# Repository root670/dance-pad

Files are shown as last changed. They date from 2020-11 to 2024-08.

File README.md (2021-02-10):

# 8020 Extruded Aluminum Dance Pad

*StepMania: Way more fun than a Pelaton bike.*

4-panel dance pad project using a frame built out of 30mm profile 8020
("T-Slot") extruded aluminum including a bar with 9 arrow panels following a
similar design to StepManiaX pads. Each directional arrow has a PCB containing
25 WS2812B RGB LEDs and 4 FSR sensors connected to a Main PCB that acts as a
breakout for a Teensy 4.1.

The firmware reads values from 16 sensors and reports them as gamepad inputs.
I'm using homemade sensors created with two 150mm strips of 1/4" copper tape
attached to 160mm x 20mm transparency film with 4mil Velostat placed across the
top. Wires are soldered to each of the copper tape strips and terminate to
JST-XE connectors at the end to connect to the Arrow Panel PCB. According to
papers I've read, creating FSR in this way will likely lead to less drifting
over time compared to "sandwich" style sensors where Velostat is placed between
two pieces of copper tape. This is similar to the method used by
commercially-produced FSRs.

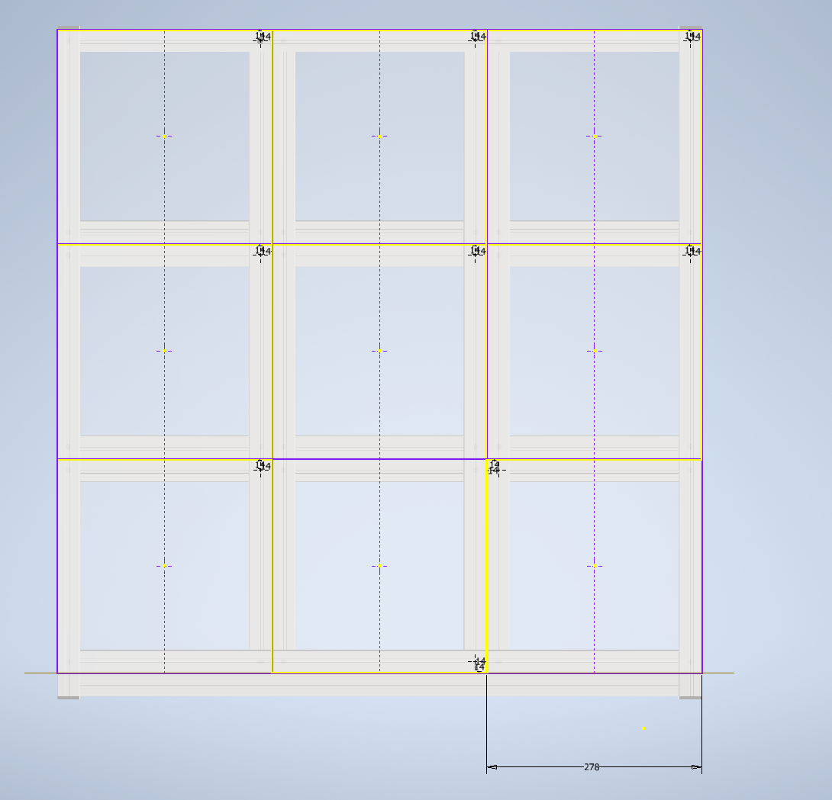
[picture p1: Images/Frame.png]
Frame


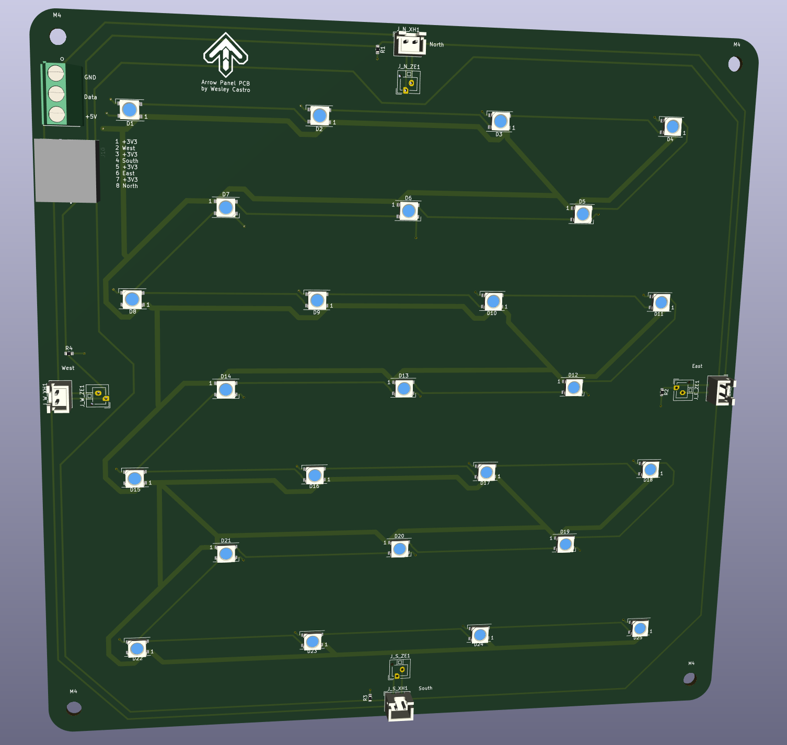
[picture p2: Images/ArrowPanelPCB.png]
Arrow Panel PCB


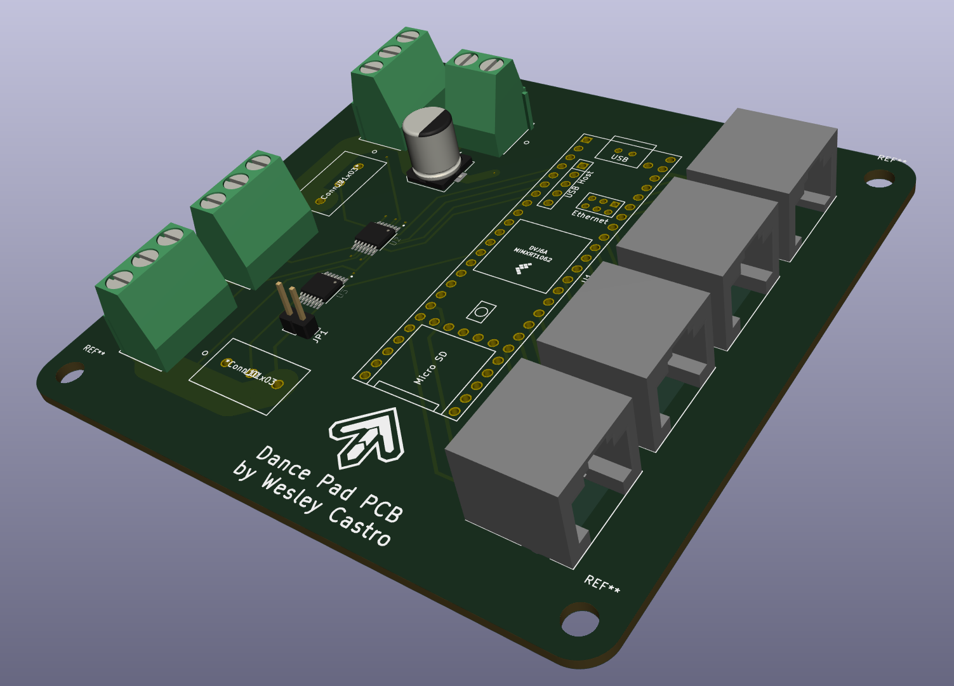
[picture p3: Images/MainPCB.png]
Main PCB


## Motivation

There has been a ton of interest in using force sensitive resistors in dance
pads recently to replace contact-based sensors and many designs have been
created. I decided to create a design for a full pad that is durable but doesn't
require power tools to build. I also wanted to gain experience using Inventor
and KiCad and share my design with others who may find it useful. It's certainly
not the best design, but the experience I've gained in the process is
invaluable.

Having personal projects to come back to is a great and productive way to
improve your creative and technical skills, especially during COVID times. And
when the project involves maintaining your physical health, that's even better! I
can't stress enough how rewarding it is to start a project, work on in over the
course of a few months, and see it through to completion. Soapbox aside, I
highly recommend attempting projects for things that seem slightly out of your
abilities. You might be surprised what you're capable of if you stick with it.

## Directory Structure

* `Frame`: Inventor project for the aluminum frame. It houses nine 276mm x 276mm
  x 12mm cast acrylic panels with 2mm clearance between each edge. The back of
  the frame has slots for securing a bar.

* `Arrow PCB`: 2 layer 200mm x 200mm PCB used within each arrow containing 25
  WS2812B V5 LEDs arranged in an alternating 4,3 grid pattern and pins for 4
  FSRs connected using JST-XH and JST-ZE connectors. Created in KiCad. Each FSR
  uses a 330 ohm pull down resistor to ground. The board is connected to the
  Main PCB using a CAT6 cable for the four sensors and screw terminals for the
  LED power, ground, and data lines. The PCB can be rotated to the best location
  to route wires to the Main PCB by denoting the location in the firmware.
  M4-sized terminals are on the corners of the PCB so it can be mounted to the
  frame using 3D printed parts (TODO).

* `Main PCB`: 2 layer ~100mm x ~100mm breakout board for a Teensy 4.1. Wires
  RJ45 connectors for connections coming from 4 Arrow PCBs and screw terminals
  for up 5 LED strands interfaced through 3.3V to 5V logic converters. The
  sensor wires are decoupled with 3.3v wires in the cable to minimize
  interference. Has M4-sized screw terminal to attach to 3D printed mounting
  hardware (TODO).

* `Configurator`: Application to configure and debug the pad written in Python.
  Communicates with the firmware using a serial connection.

* `Firmware`: Code that runs on the Teensy. Reads sensor values, listens for
  serial messages, and controls the LEDs. Uses fixed timings for sending Joypad
  reports and updating the LEDs. The goal is for it to be easy enough to modify
  to support different pad layouts (i.e. 5 panel StepManiaX or Pump It Up pads)

* `Supplemental`: Various helper scripts and files related to this project. All
  of these are optional but may be useful depending on you setup.

## Status

The frame, acrylic panels, and PCB designs have been finalized, fabricated, and
assembled.

The arrows have counter bore screws but I made the larger part of the counter
bore too small (It's a 9.53mm counterbore for a 7.94mm through hole, leaving
~0.8mm radius for the counterbore. Whoops.). It's large enough to fit
button-head M5 screws with a 3D printed spacer but M6 socket and button head
screws will not fit unfortunately. These will work fine with M5 screws but the
lesson learned is to not hastily order things like this in the future :-).

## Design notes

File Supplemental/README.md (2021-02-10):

# Supplemental

Various helper scripts and files related to this project.

## Files

* `lights_bridge.py`: Python script to send output messages for lights from MAME
  to serial devices as a SextetStream. To use this, launch MAME with `-output
  network` or change the `output` setting in `mame.ini` to `network`.

* `ddr.lua`: Lua script for MAME that disables frame skip during the
  initialization sequence of DDR titles. To use this, launch MAME with
  `autoboot_script ddr.lua`.

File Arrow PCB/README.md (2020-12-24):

# Arrow Panel PCB

Board placed under each panel. Houses 25 WS2812B V5 RGB LEDs and connects to 4
FSR sensors using JST-XE or JST-ZH connectors. Connects back to the Main PCB
using a CAT6 cable for the sensors and cables secured to a screw terminal for
the lights.

## Notes

* The pull down resistor used for each sensor may need to be adjusted depending
  on the sensors being used.
* The board requires the "V5" revision of the WS2812B LEDs. The advantage of
  this version is that have an internal capacitor so you don't the need to place
  an external capacitor between the positive voltage and ground pins. If an
  older version is used the LEDs will likely be damaged when they receive power.

## Issues

* I was unable to get the LEDs to work reliably using multiple 3.3v and 5v
  microcontrollers and WS2812B libraries. I believe there is something wrong
  with my design or the LEDs sourced by LCSC were not actually the 5V
  variations. LCSC has been unable to confirm if they are actually the V5
  version.
* The PCB is too big to fit within the frame underneath the panels when using
  corner brackets. As a workaround the PCBs need to be placed underneath the
  frame.

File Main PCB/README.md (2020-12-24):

# Main PCB

Breakout board for a Teensy 4.1 with 4 RJ45 connectors to connect the sensors
from each arrow and 5 3-pin screw terminals to connect the lights. An additional
3-pin screw terminal is available for an auxilary lighting strip.

## Notes

* At least a 6A 5V DC power supply is needed to support displaying all LEDs at
  maximum brightness.

## Issues

* The LED pins for the four arrows  don't allow for "parallel output" with
  FastLED or WS2812Serial because I didn't realize only a subset of pins support
  that feature. The AuxLED pin however should work with parallel output.
* Silkscreen labels are missing for most connectors.

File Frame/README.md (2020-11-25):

# Frame

Frame designed in Inventor 2021 using 30mm 8020 aluminum extrusions.

## Notes

* My design uses a 975mm high bar secured to the bottom row of the pad but it is
   not included in the Inventor project.
* The panels are 276mm x 276mm x 12mm cast acrylic with 3.17mm (1/8") rounded
   corners (note that the drawin shows these as 2mm, but the shop that
   fabricated them (TAP Plastics) only had a 1/8" roundover bit) and counterbore screws. They
   support M5 screws with a ~2mm OD standoff. The standoffs should allow for
   consistent pressure across all panels. A drawing of the panel specifications
   can be found in `Arrow Panel.pdf`.
* I plan to use 5/16" thick HDPE foaming underneath the corners of each panel
   but have not finalized this aspect.
* The stationary arrows will need risers to make them ~4mm higher than the arrow
  panels. This can be done with metal washers or 3D printed inserts.
* There are 2mm of space between the edges of each arrow.
* The assembly requires an 8020 frame generator library to be added to the
   content center to load correctly:
   https://grabcad.com/library/8020-profile-extrusions-and-inventor-frame-generator-library-content-center-1

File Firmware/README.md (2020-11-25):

# Dance Pad Firmware

Firmware for implementing a dance pad. Analog sensor inputs are converted to
buttons on an HID joypad.

## Features

* Auto-calibration of FSR sensors using a moving baseline.
* Serial interface for configuration and debugging.

## Features (planned)

* Activate RBG LEDs in arrow PCBs based on SextetStream protocol over Serial interface.

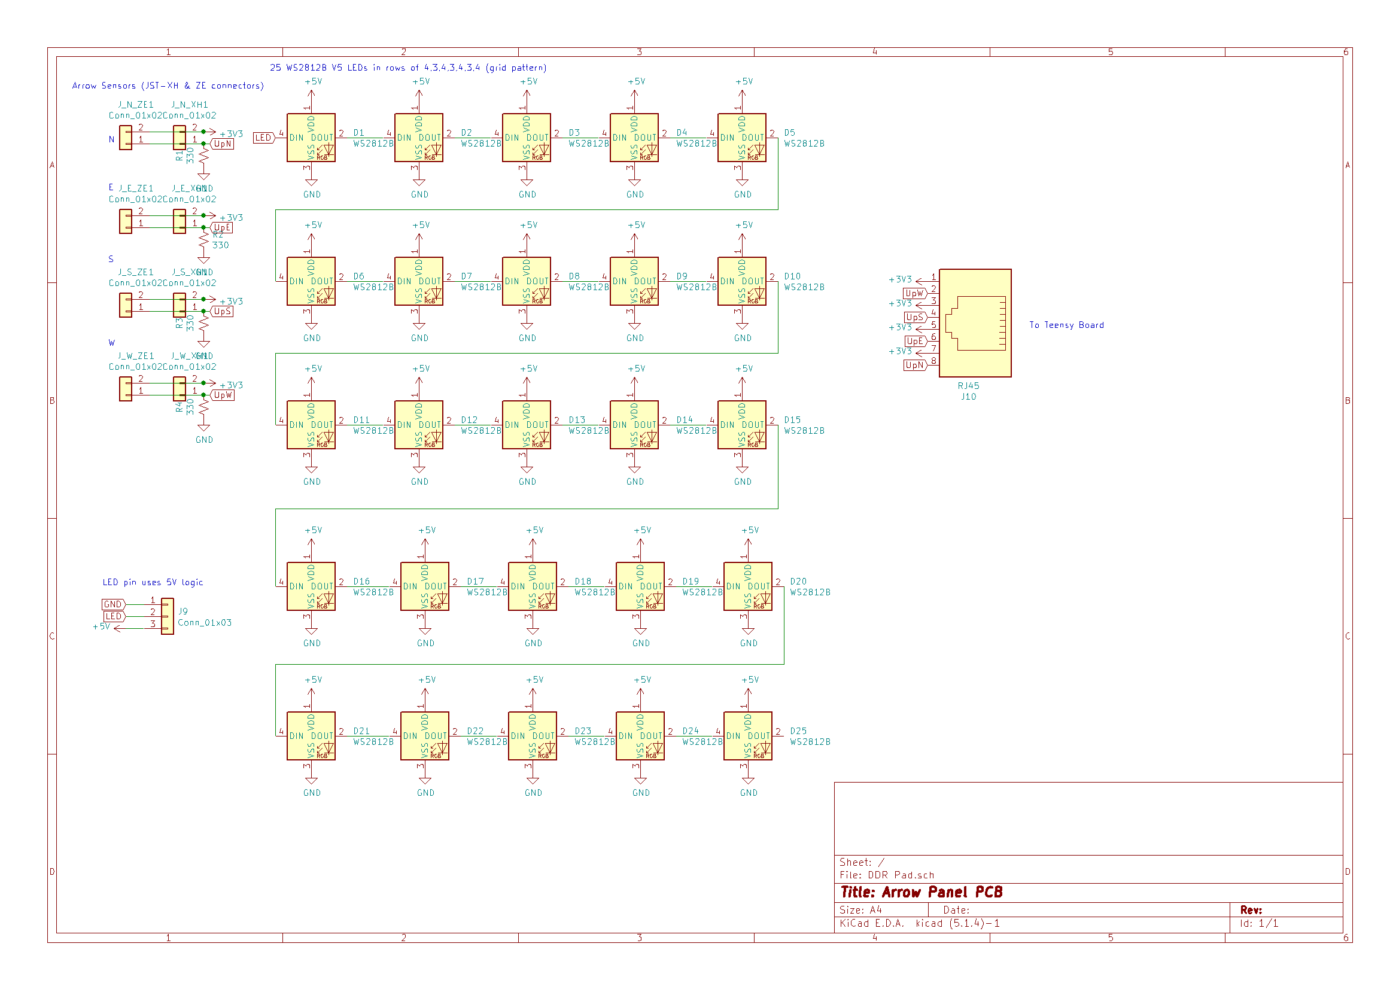
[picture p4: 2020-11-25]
Arrow PCB/Schematic.png

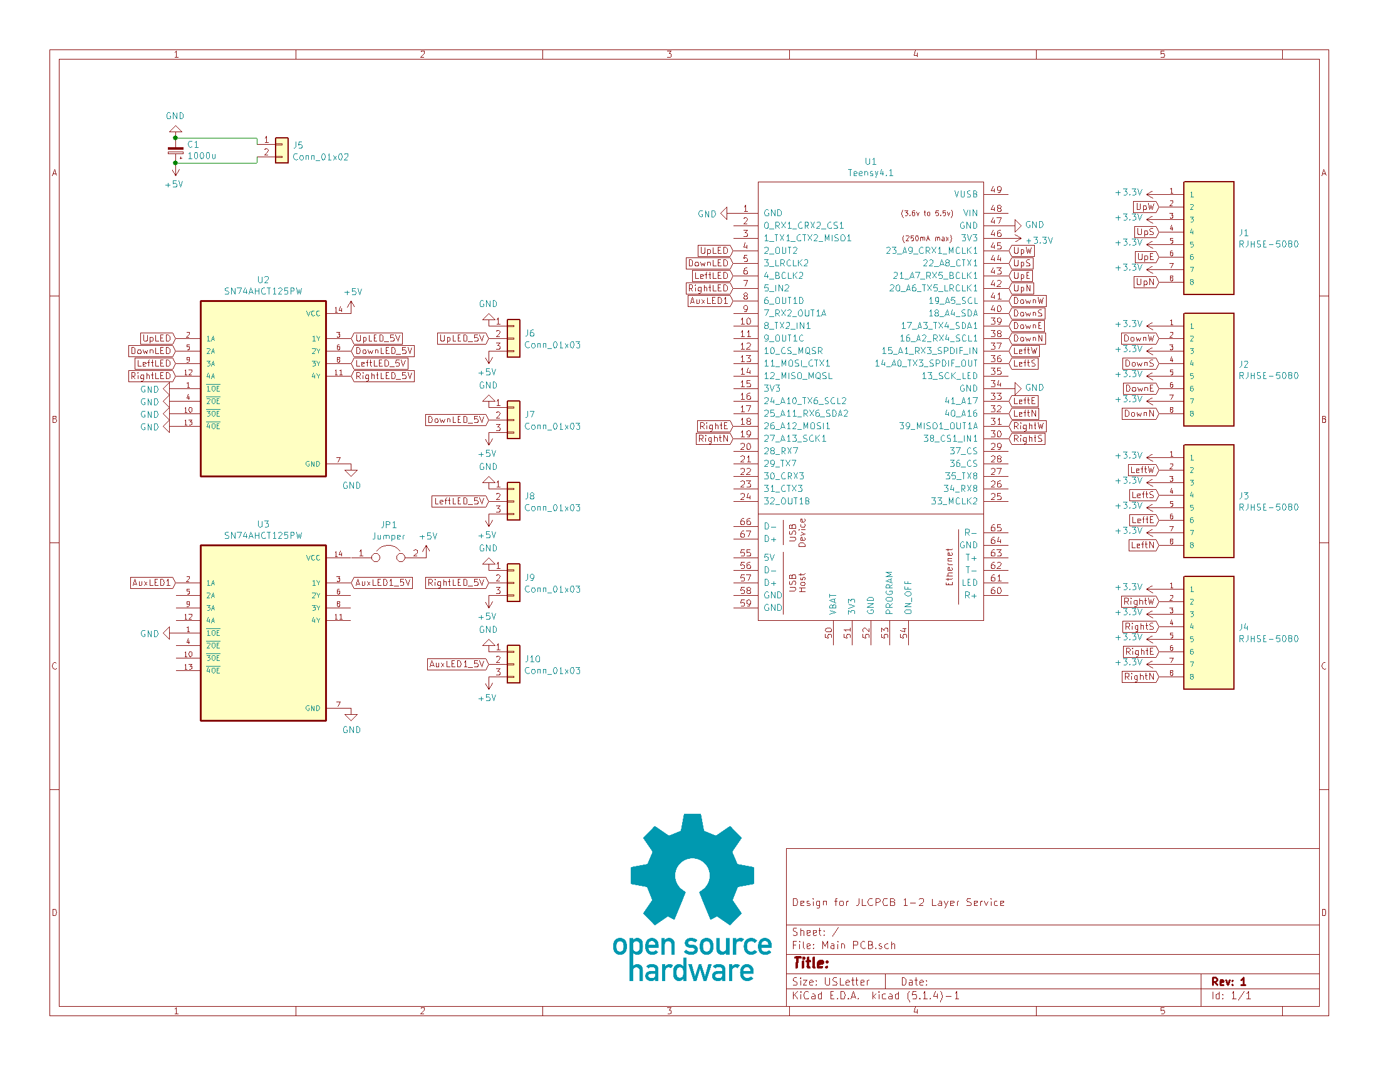
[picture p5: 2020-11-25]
Main PCB/Schematic.png

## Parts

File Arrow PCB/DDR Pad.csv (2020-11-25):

Comment | Designator | Footprint | LCSC
WS2812B | D1,D2,D3,D4,D5,D6,D7,D8,D9,D10,D11,D12,D13,D14,D15,D16,D17,D18,D19,D20,D21,D22,D23,D24,D25 | LED_SMD:LED_WS2812B_PLCC4_5.0x5.0mm_P3.2mm
RJ45 | J10 | RJHSE-5080:AMPHENOL_RJHSE-5080
Conn_01x03 | J9 | footprints:1935174
Conn_01x02 | J_E_ZE1,J_S_ZE1,J_W_ZE1,J_N_ZE1 | Connector_JST:JST_ZE_B02B-ZESK-1D_1x02_P1.50mm_Vertical
Conn_01x02 | J_N_XH1,J_E_XH1,J_S_XH1,J_W_XH1 | Connector_JST:JST_XH_B2B-XH-A_1x02_P2.50mm_Vertical
330 | R1,R2,R3,R4 | Resistor_SMD:R_0603_1608Metric

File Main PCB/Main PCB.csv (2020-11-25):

Comment | Designator | Footprint | LCSC
1000u | C1 | Capacitor_SMD:CP_Elec_8x10 | C134755
RJHSE-5080 | J1,J2,J3,J4 | RJHSE-5080:AMPHENOL_RJHSE-5080
Conn_01x02 | J5 | footprints:1935161
Conn_01x03 | J6,J7,J8,J9,J10 | footprints:1935174
Jumper | JP1 | Connector_PinHeader_2.54mm:PinHeader_1x02_P2.54mm_Vertical
Teensy4.1 | U1 | Main PCB:Teensy41
SN74AHCT125PW | U2,U3 | SN74AHCT125PW:SOP65P640X120-14N | C36365

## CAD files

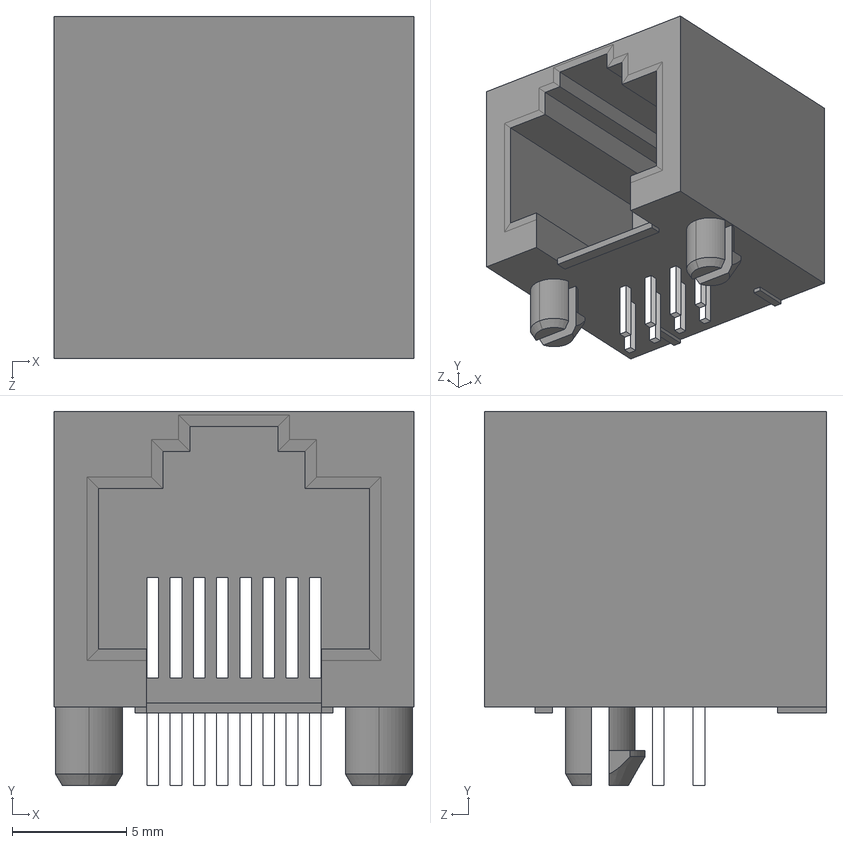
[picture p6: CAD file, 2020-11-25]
Arrow PCB/RJHSE-5080/RJHSE-5080.step
15.7 x 16.4 x 15.0 mm

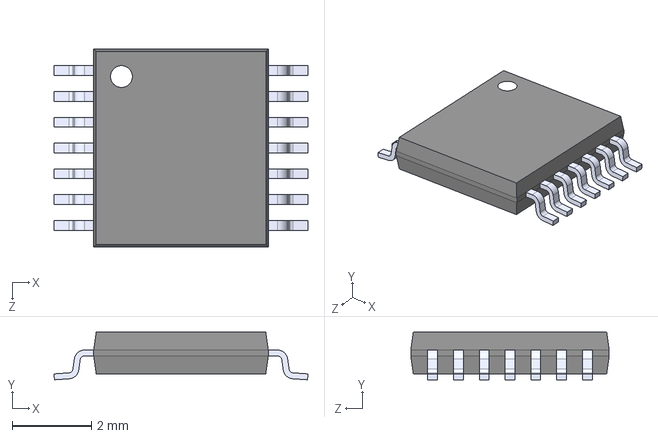
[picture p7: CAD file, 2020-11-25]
Main PCB/SN74AHCT125PW/SN74AHCT125PW.step
6.40 x 1.20 x 5.00 mm

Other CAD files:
Arrow PCB/DDR Pad 1.ipt
Arrow PCB/DDR Pad.ipt
Frame/30mm.iam
Frame/30mm/Frame/1604985380858.ipt
Frame/30mm/Frame/1604985393171.ipt
Frame/30mm/Frame/1604985569969.ipt
Frame/30mm/Frame/1604985569996.ipt
Frame/30mm/Frame/1604985570023.ipt
Frame/30mm/Frame/1604985570057.ipt
Frame/30mm/Frame/1604985570057.newVer.ipt
Frame/30mm/Frame/1604985570084.ipt
Frame/30mm/Frame/1604985570084.newVer.ipt
Frame/30mm/Frame/1604985570111.ipt
Frame/30mm/Frame/1604985570138.ipt
Frame/30mm/Frame/1604985570165.ipt
Frame/30mm/Frame/1604985570191.ipt
Frame/30mm/Frame/1604985708951.ipt
Frame/30mm/Frame/1605505222055.ipt
Frame/30mm/Frame/1605505434790.ipt
Frame/30mm/Frame/Frame 1604985372804.iam
Frame/30mm/Frame/OldVersions/1604985380858.0004.ipt
Frame/30mm/Frame/OldVersions/1604985393171.0004.ipt
Frame/30mm/Frame/OldVersions/1604985569969.0004.ipt
Frame/30mm/Frame/OldVersions/1604985569996.0004.ipt
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

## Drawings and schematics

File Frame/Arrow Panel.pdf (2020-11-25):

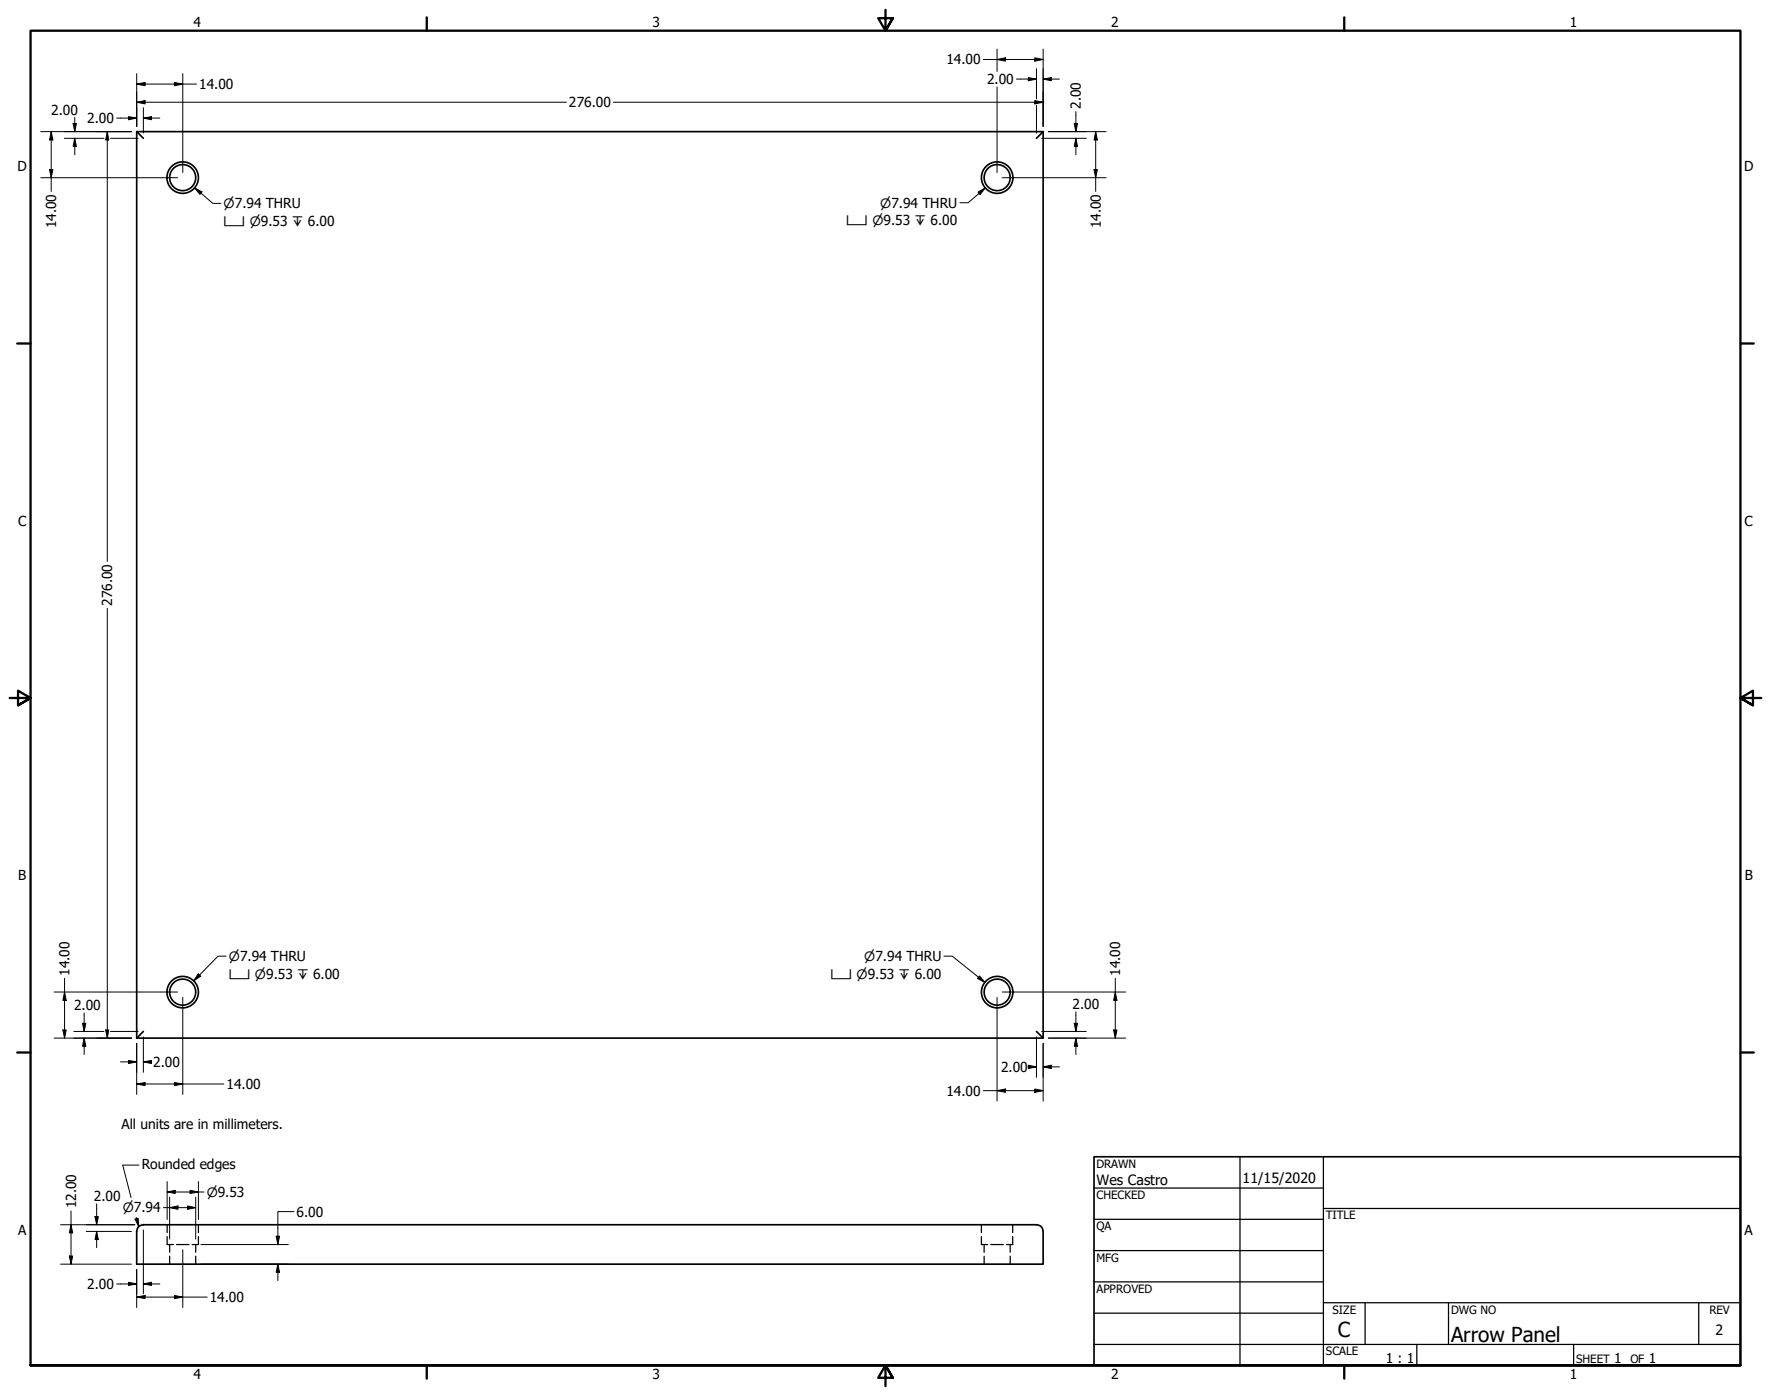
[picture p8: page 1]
Rounded edges

All units are in millimeters.

DRAWN Wes Castro | 11/15/2020

CHECKED

MFG

APPROVED

SIZE C | DWG NO Arrow Panel | REV 2

SCALE 1 : 1 | | SHEET 1 OF 1

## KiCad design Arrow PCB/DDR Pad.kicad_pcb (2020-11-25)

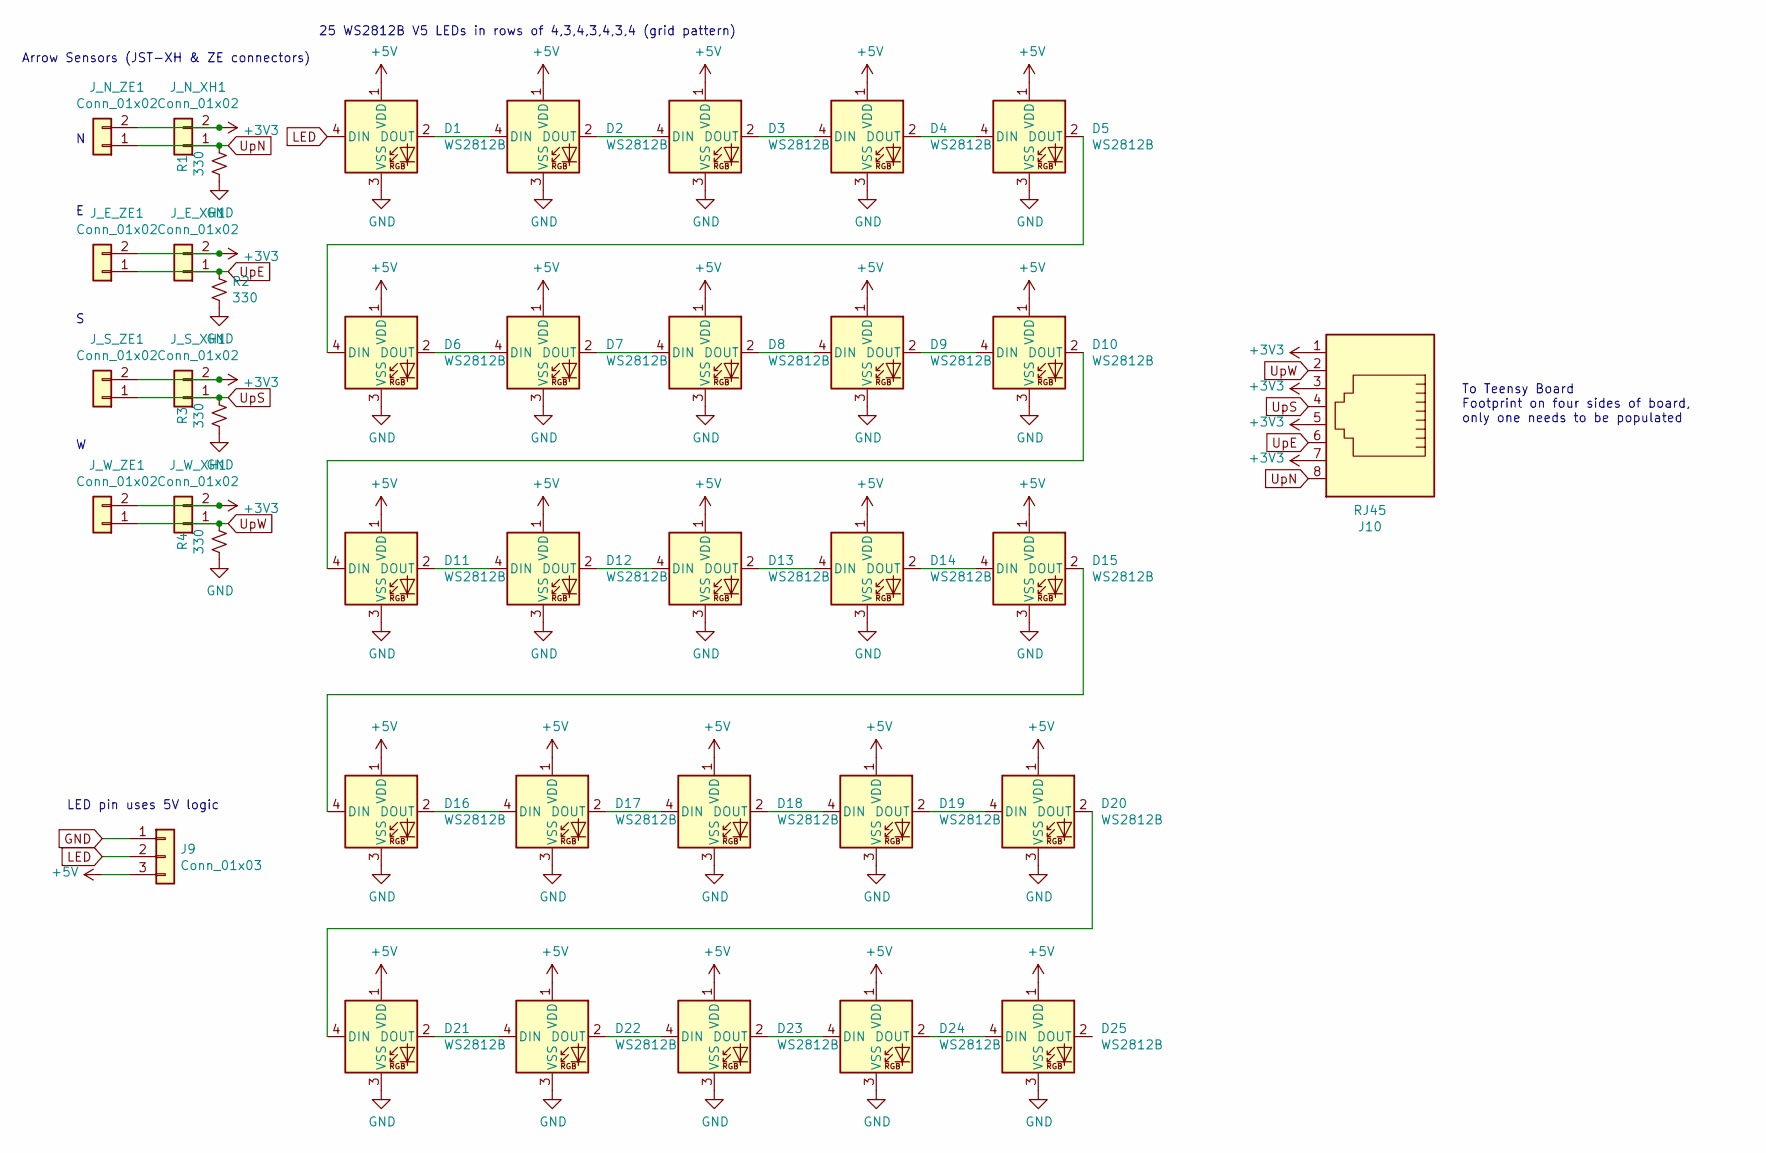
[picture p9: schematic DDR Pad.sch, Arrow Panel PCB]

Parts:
D1, D2, D3, D4, D5, D6, D7, D8, D9, D10, D11, D12, D13, D14, D15, D16, D17, D18, D19, D20, D21, D22, D23, D24, D25: WS2812B; LED_WS2812B_PLCC4_5.0x5.0mm_P3.2mm
J9: Conn_01x03; 1935174
J10: RJ45; AMPHENOL_RJHSE-5080
J_E_XH1: Conn_01x02; JST_XH_B2B-XH-A_1x02_P2.50mm_Vertical
J_E_ZE1: Conn_01x02; JST_ZE_B02B-ZESK-1D_1x02_P1.50mm_Vertical
J_N_XH1: Conn_01x02; JST_XH_B2B-XH-A_1x02_P2.50mm_Vertical
J_N_ZE1: Conn_01x02; JST_ZE_B02B-ZESK-1D_1x02_P1.50mm_Vertical
J_S_XH1: Conn_01x02; JST_XH_B2B-XH-A_1x02_P2.50mm_Vertical
J_S_ZE1: Conn_01x02; JST_ZE_B02B-ZESK-1D_1x02_P1.50mm_Vertical
J_W_XH1: Conn_01x02; JST_XH_B2B-XH-A_1x02_P2.50mm_Vertical
J_W_ZE1: Conn_01x02; JST_ZE_B02B-ZESK-1D_1x02_P1.50mm_Vertical
R1, R2, R3, R4: 330; R_0603_1608Metric

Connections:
+3V3: J10.1, J10.3, J10.5, J10.7, J_E_XH1.2, J_E_ZE1.2, J_N_XH1.2, J_N_ZE1.2, J_S_XH1.2, J_S_ZE1.2, J_W_XH1.2, J_W_ZE1.2
+5V: D1.1 (VDD), D2.1 (VDD), D3.1 (VDD), D4.1 (VDD), D5.1 (VDD), D6.1 (VDD), D7.1 (VDD), D8.1 (VDD), D9.1 (VDD), D10.1 (VDD), D11.1 (VDD), D12.1 (VDD), D13.1 (VDD), D14.1 (VDD), D15.1 (VDD), D16.1 (VDD), D17.1 (VDD), D18.1 (VDD), D19.1 (VDD), D20.1 (VDD), D21.1 (VDD), D22.1 (VDD), D23.1 (VDD), D24.1 (VDD), D25.1 (VDD), J9.3
GND: D1.3 (VSS), D2.3 (VSS), D3.3 (VSS), D4.3 (VSS), D5.3 (VSS), D6.3 (VSS), D7.3 (VSS), D8.3 (VSS), D9.3 (VSS), D10.3 (VSS), D11.3 (VSS), D12.3 (VSS), D13.3 (VSS), D14.3 (VSS), D15.3 (VSS), D16.3 (VSS), D17.3 (VSS), D18.3 (VSS), D19.3 (VSS), D20.3 (VSS), D21.3 (VSS), D22.3 (VSS), D23.3 (VSS), D24.3 (VSS), D25.3 (VSS), J9.1, R1.2, R2.2, R3.2, R4.2
LED: D1.4 (DIN), J9.2
unnamed: D1.2 (DOUT), D2.4 (DIN)
unnamed: D2.2 (DOUT), D3.4 (DIN)
unnamed: D3.2 (DOUT), D4.4 (DIN)
unnamed: D4.2 (DOUT), D5.4 (DIN)
unnamed: D5.2 (DOUT), D6.4 (DIN)
unnamed: D6.2 (DOUT), D7.4 (DIN)
unnamed: D7.2 (DOUT), D8.4 (DIN)
unnamed: D8.2 (DOUT), D9.4 (DIN)
unnamed: D10.2 (DOUT), D11.4 (DIN)
unnamed: D9.2 (DOUT), D10.4 (DIN)
unnamed: D11.2 (DOUT), D12.4 (DIN)
unnamed: D12.2 (DOUT), D13.4 (DIN)
unnamed: D13.2 (DOUT), D14.4 (DIN)
unnamed: D14.2 (DOUT), D15.4 (DIN)
unnamed: D15.2 (DOUT), D16.4 (DIN)
unnamed: D16.2 (DOUT), D17.4 (DIN)
unnamed: D17.2 (DOUT), D18.4 (DIN)
unnamed: D18.2 (DOUT), D19.4 (DIN)
unnamed: D19.2 (DOUT), D20.4 (DIN)
unnamed: D20.2 (DOUT), D21.4 (DIN)
unnamed: D21.2 (DOUT), D22.4 (DIN)
unnamed: D22.2 (DOUT), D23.4 (DIN)
unnamed: D23.2 (DOUT), D24.4 (DIN)
unnamed: D24.2 (DOUT), D25.4 (DIN)
UpE: J10.6, J_E_XH1.1, J_E_ZE1.1, R2.1
UpN: J10.8, J_N_XH1.1, J_N_ZE1.1, R1.1
UpS: J10.4, J_S_XH1.1, J_S_ZE1.1, R3.1
UpW: J10.2, J_W_XH1.1, J_W_ZE1.1, R4.1

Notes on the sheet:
LED pin uses 5V logic
Arrow Sensors (JST-XH & ZE connectors)
25 WS2812B V5 LEDs in rows of 4,3,4,3,4,3,4 (grid pattern)
To Teensy Board Footprint on four sides of board, only one needs to be populated

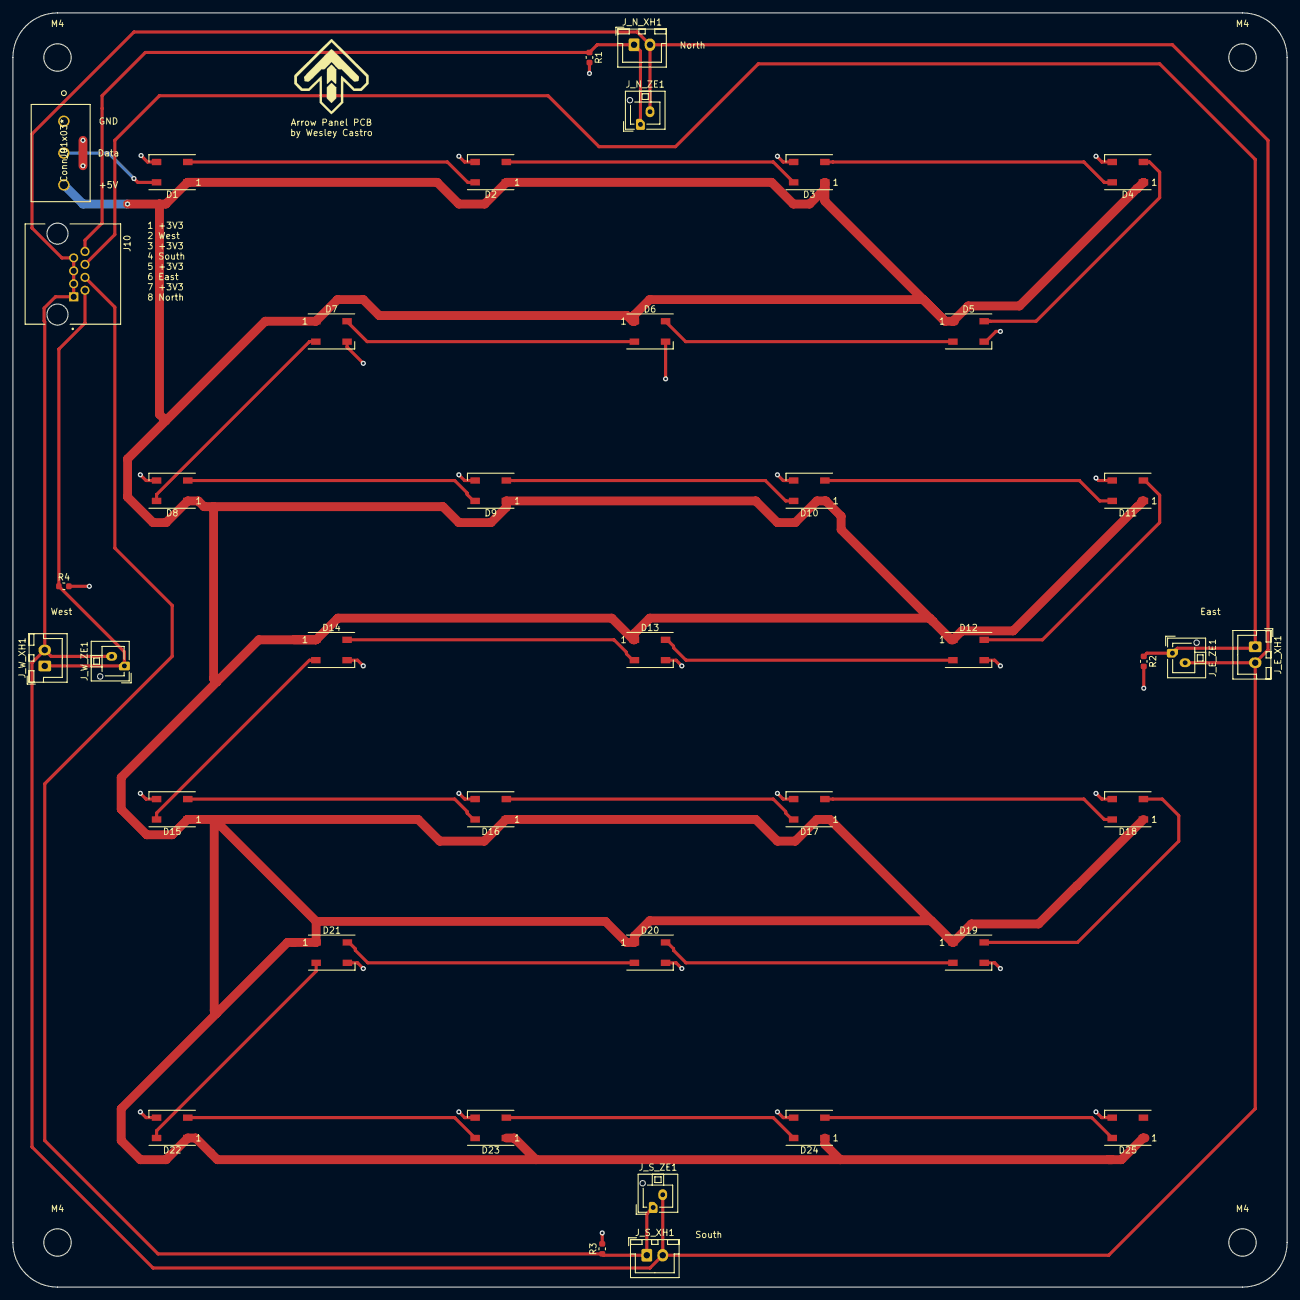
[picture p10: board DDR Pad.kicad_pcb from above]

Board: 2 copper layers, 200.0 x 200.0 mm, 43 parts (0 on the bottom side), 32 nets.

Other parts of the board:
M4, M4#2, M4#3, M4#4: MountingHole_4.3mm_M4

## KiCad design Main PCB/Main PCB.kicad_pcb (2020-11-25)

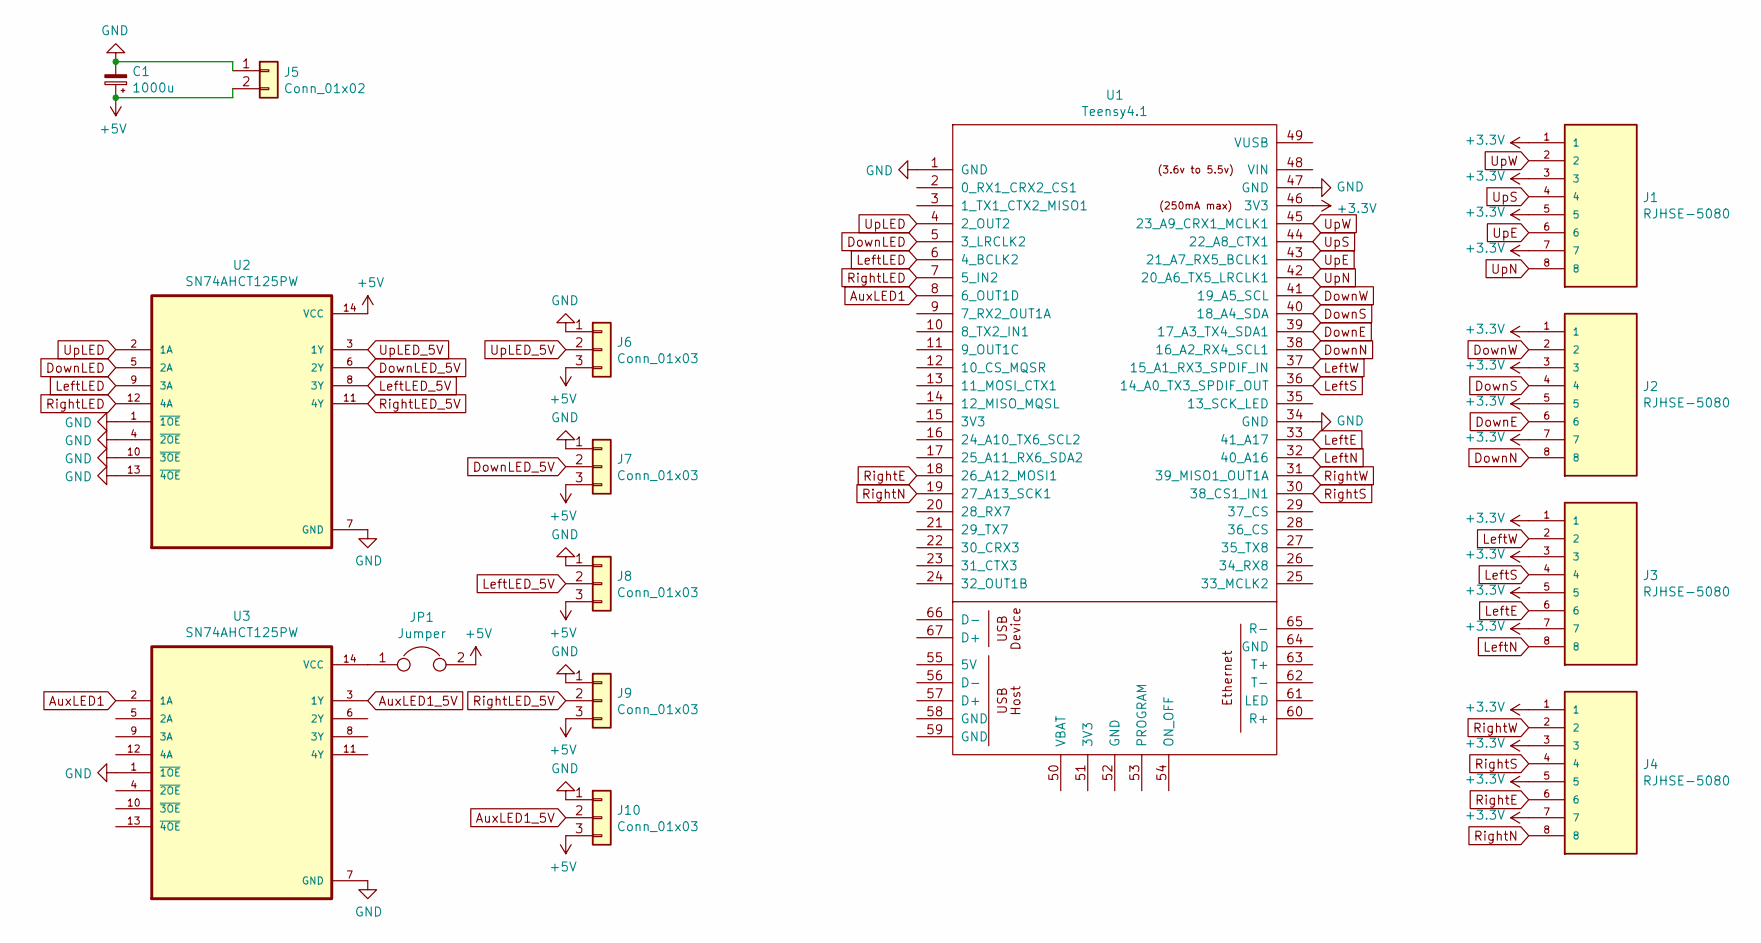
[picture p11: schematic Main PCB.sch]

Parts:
C1: 1000u; CP_Elec_8x10; LCSC C134755
J1, J2, J3, J4: RJHSE-5080; AMPHENOL_RJHSE-5080; PARTREV G
J5: Conn_01x02; 1935161
J6, J7, J8, J9, J10: Conn_01x03; 1935174
JP1: Jumper; PinHeader_1x02_P2.54mm_Vertical
U1: Teensy4.1; Teensy41
U2, U3: SN74AHCT125PW; SOP65P640X120-14N

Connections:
+3V3: J1.1, J1.3, J1.5, J1.7, J2.1, J2.3, J2.5, J2.7, J3.1, J3.3, J3.5, J3.7, J4.1, J4.3, J4.5, J4.7, U1.46 (3V3)
+5V: C1.1, J5.2, J6.3, J7.3, J8.3, J9.3, J10.3, JP1.2, U2.14 (VCC)
AuxLED1: U1.8 (6_OUT1D), U3.2 (1A)
AuxLED1_5V: J10.2, U3.3 (1Y)
DownE: J2.6, U1.39 (17_A3_TX4_SDA1)
DownLED: U1.5 (3_LRCLK2), U2.5 (2A)
DownLED_5V: J7.2, U2.6 (2Y)
DownN: J2.8, U1.38 (16_A2_RX4_SCL1)
DownS: J2.4, U1.40 (18_A4_SDA)
DownW: J2.2, U1.41 (19_A5_SCL)
GND: C1.2, J5.1, J6.1, J7.1, J8.1, J9.1, J10.1, U1.1 (GND), U1.34 (GND), U1.47 (GND), U2.1 (~1OE), U2.4 (~2OE), U2.7 (GND), U2.10 (~3OE), U2.13 (~4OE), U3.1 (~1OE), U3.7 (GND)
LeftE: J3.6, U1.33 (41_A17)
LeftLED: U1.6 (4_BCLK2), U2.9 (3A)
LeftLED_5V: J8.2, U2.8 (3Y)
LeftN: J3.8, U1.32 (40_A16)
LeftS: J3.4, U1.36 (14_A0_TX3_SPDIF_OUT)
LeftW: J3.2, U1.37 (15_A1_RX3_SPDIF_IN)
unnamed: JP1.1, U3.14 (VCC)
RightE: J4.6, U1.18 (26_A12_MOSI1)
RightLED: U1.7 (5_IN2), U2.12 (4A)
RightLED_5V: J9.2, U2.11 (4Y)
RightN: J4.8, U1.19 (27_A13_SCK1)
RightS: J4.4, U1.30 (38_CS1_IN1)
RightW: J4.2, U1.31 (39_MISO1_OUT1A)
UpE: J1.6, U1.43 (21_A7_RX5_BCLK1)
UpLED: U1.4 (2_OUT2), U2.2 (1A)
UpLED_5V: J6.2, U2.3 (1Y)
UpN: J1.8, U1.42 (20_A6_TX5_LRCLK1)
UpS: J1.4, U1.44 (22_A8_CTX1)
UpW: J1.2, U1.45 (23_A9_CRX1_MCLK1)

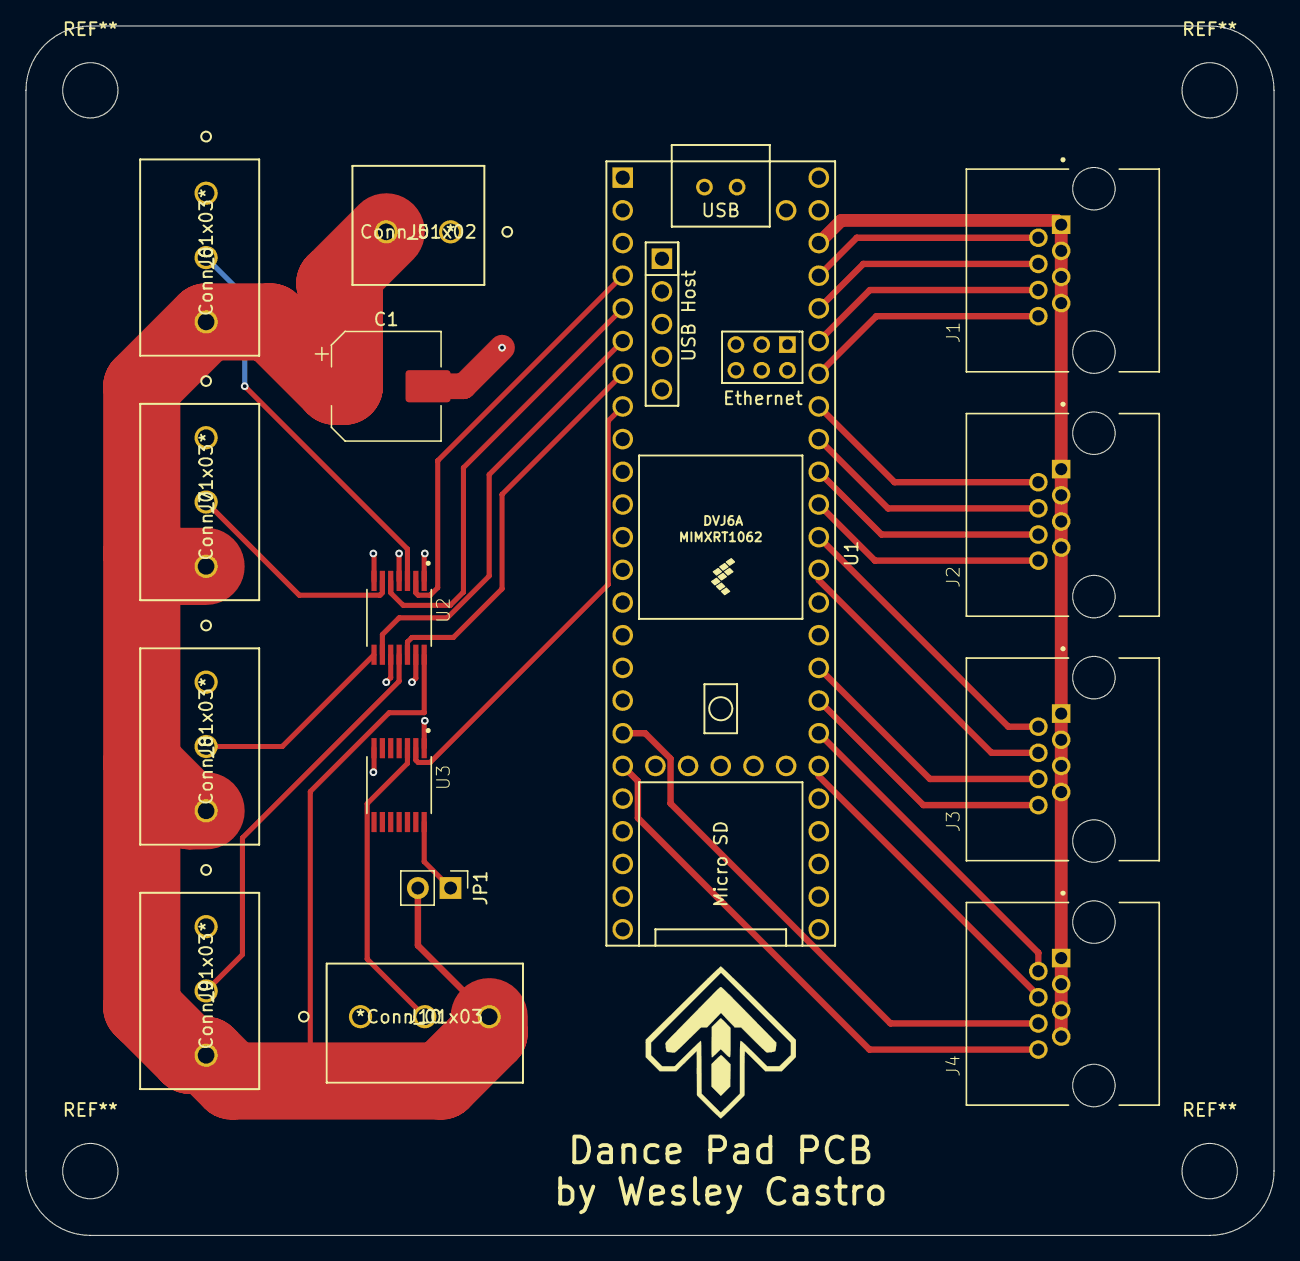
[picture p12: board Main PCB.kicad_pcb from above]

Board: 4 copper layers, 97.0 x 94.0 mm, 15 parts (0 on the bottom side), 30 nets.

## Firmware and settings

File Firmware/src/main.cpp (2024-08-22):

//
// Dance Pad Firmware
//
// * Auto-calibration of FSR sensors using a moving baseline.
// * Activate RBG LEDs in arrow PCBs based on SextetStream input.
// * Serial console for obtaining sensor data and reading/writing configuration.
//
#include <Arduino.h>
#include <Keyboard.h>
#include <array>

#include "Config.h"
#include "Lighting.h"
#include "Panel.h"

static String s_strVersion;
static char s_pSextetStream[14]; // Includes newline characteam

// Pins for sensors based on layout of the Dance Pad PCB
#define PIN_UP_N    A6
#define PIN_UP_E    A7
#define PIN_UP_S    A8
#define PIN_UP_W    A9
#define PIN_DOWN_N  A2
#define PIN_DOWN_E  A3
#define PIN_DOWN_S  A4
#define PIN_DOWN_W  A5
#define PIN_LEFT_N  A16
#define PIN_LEFT_E  A17
#define PIN_LEFT_S  A0
#define PIN_LEFT_W  A1
#define PIN_RIGHT_N A13
#define PIN_RIGHT_E A12
#define PIN_RIGHT_S A14
#define PIN_RIGHT_W A15

static Panel s_panelUp(
  enumPanelUp, enumPanelOrientation0, PIN_UP_N, PIN_UP_E, PIN_UP_S, PIN_UP_W);
static Panel s_panelDown(
  enumPanelDown,
  enumPanelOrientation270,
  PIN_DOWN_N,
  PIN_DOWN_E,
  PIN_DOWN_S,
  PIN_DOWN_W);
static Panel s_panelLeft(
  enumPanelLeft,
  enumPanelOrientation270,
  PIN_LEFT_N,
  PIN_LEFT_E,
  PIN_LEFT_S,
  PIN_LEFT_W);
static Panel s_panelRight(
  enumPanelRight,
  enumPanelOrientation0,
  PIN_RIGHT_N,
  PIN_RIGHT_E,
  PIN_RIGHT_S,
  PIN_RIGHT_W);

// Joystick button mapping
#define JOY_UP_BUTTON    1
#define JOY_DOWN_BUTTON  2
#define JOY_LEFT_BUTTON  3
#define JOY_RIGHT_BUTTON 4

// Scheduling
const uint32_t kJoystickUpdateFrequency = 1000;
const uint32_t kLEDUpdateFrequency = 100;

// Force calibration of sensors in each panel
void calibratePanels() {
  s_panelUp.calibrate();
  s_panelDown.calibrate();
  s_panelLeft.calibrate();
  s_panelRight.calibrate();
}

// Update sensor readings from each panel
void updatePanels() {
  s_panelUp.update();
  s_panelDown.update();
  s_panelLeft.update();
  s_panelRight.update();
}

void setup() {
  delay(1000);
  s_strVersion.concat("Dance Pad Firmware " __DATE__);
  s_strVersion.concat(' ');
  s_strVersion.concat(__TIME__);

  pinMode(LED_BUILTIN, OUTPUT);

  Configuration::getInstance()->read();

  Serial.begin(9600);

  calibratePanels();

  // Joystick.useManualSend(true);
  // Joystick.hat(-1);
  // Joystick.X(512);
  // Joystick.Y(512);
  // Joystick.Z(512);

  for (int i = 0; i < 3; i++) {
    CRGB color(i == 0 ? 255 : 0, i == 1 ? 255 : 0, i == 2 ? 255 : 0);
    Lights::getInstance()->illuminateStrip(enumLightsUpArrow, color);
    Lights::getInstance()->illuminateStrip(enumLightsDownArrow, color);
    Lights::getInstance()->illuminateStrip(enumLightsLeftArrow, color);
    Lights::getInstance()->illuminateStrip(enumLightsRightArrow, color);
    Lights::getInstance()->update();
    FastLED.show();
    FastLED.delay(200);
  }
}

void printSensorValues() {
  // name:value,name:value, ...
  Serial.print("Min:0,Max:1023,");
  Serial.print("UpN:");
  // Serial.println(analogRead(PIN_UP_N));
  Serial.print(analogRead(PIN_UP_N));
  Serial.print(",");
  Serial.print("UpE:");
  Serial.print(analogRead(PIN_UP_E));
  Serial.print(",");
  Serial.print("UpS:");
  Serial.print(analogRead(PIN_UP_S));
  Serial.print(",");
  Serial.print("UpW:");
  Serial.print(analogRead(PIN_UP_W));
  Serial.print(",");

  Serial.print("DownN:");
  Serial.print(analogRead(PIN_DOWN_N));
  Serial.print(",");
  Serial.print("DownE:");
  Serial.print(analogRead(PIN_DOWN_E));
  Serial.print(",");
  Serial.print("DownS:");
  Serial.print(analogRead(PIN_DOWN_S));
  Serial.print(",");
  Serial.print("DownW:");
  Serial.print(analogRead(PIN_DOWN_W));
  Serial.print(",");

  Serial.print("LeftN:");
  Serial.print(analogRead(PIN_LEFT_N));
  Serial.print(",");
  Serial.print("LeftE:");
  Serial.print(analogRead(PIN_LEFT_E));
  Serial.print(",");
  Serial.print("LeftS:");
  Serial.print(analogRead(PIN_LEFT_S));
  Serial.print(",");
  Serial.print("LeftW:");
  Serial.print(analogRead(PIN_LEFT_W));
  Serial.print(",");

  Serial.print("RightN:");
  Serial.print(analogRead(PIN_RIGHT_N));
  Serial.print(",");
  Serial.print("RightE:");
  Serial.print(analogRead(PIN_RIGHT_E));
  Serial.print(",");
  Serial.print("RightS:");
  Serial.print(analogRead(PIN_RIGHT_S));
  Serial.print(",");
  Serial.print("RightW:");
  Serial.println(analogRead(PIN_RIGHT_W));
}

void decodeSextetStream() {
  // Player 1 pad lights
  Lights::getInstance()->setStatus(
    enumLightsLeftArrow, s_pSextetStream[3] & 0x01);
  Lights::getInstance()->setStatus(
    enumLightsRightArrow, s_pSextetStream[3] & 0x02);
  Lights::getInstance()->setStatus(
    enumLightsUpArrow, s_pSextetStream[3] & 0x04);
  Lights::getInstance()->setStatus(
    enumLightsDownArrow, s_pSextetStream[3] & 0x08);
}

// Process data sent over the serial connection
//
// Input data can either be lighting data in SextetStream format or a command.
// When the input is lighting data, no response is sent. All commands are
// prefixed with `-` and terminated with a newline character. Commands may have
// a single-line response terminated with a newline character (`\n`).
class SerialProcessor {
public:
  SerialProcessor() {
    m_strCommand.reserve(32);
    m_strResponse.reserve(1024);
  }

  void update() {
    if (Serial.available()) {
      char c = Serial.read();
      if (c >= 0x30 && c <= 0x6F) {
        // Light state. Read remaining 13 bytes of stream
        s_pSextetStream[0] = c;
        Serial.readBytes(s_pSextetStream + 1, 13);

        // Update the lights
        decodeSextetStream();
      } else if (c == '-') {
        // Command terminated by newline
        m_strCommand = Serial.readStringUntil('\n');
        m_strCommand.trim();
        m_strResponse = "";

        if (m_strCommand.equalsIgnoreCase(kCmdVersion)) {
          onCommandVersion();
        } else if (m_strCommand.equalsIgnoreCase(kCmdBlink)) {
          onCommandBlink();
        } else if (m_strCommand.equalsIgnoreCase(kCmdGetConfig)) {
          onCommandGetConfig();
        } else if (m_strCommand.equalsIgnoreCase(kCmdSetConfig)) {
          onCommandSetConfig();
        } else if (m_strCommand.equalsIgnoreCase(kCmdPersist)) {
          onCommandPersist();
        } else if (m_strCommand.equalsIgnoreCase(kCmdReset)) {
          onCommandReset();
        } else if (m_strCommand.equalsIgnoreCase(kCmdValues)) {
          onCommandGetValues();
        } else if (m_strCommand.equalsIgnoreCase(kCmdCalibrate)) {
          calibratePanels();
        } else {
          m_strResponse = "Unknown command";
        }

        if (m_strResponse.length() > 0) {
          Serial.println(m_strResponse);
        }
      }
    }
  }

private:
  static const String kCmdVersion;
  static const String kCmdBlink;
  static const String kCmdGetConfig;
  static const String kCmdSetConfig;
  static const String kCmdPersist;
  static const String kCmdReset;
  static const String kCmdValues;
  static const String kCmdCalibrate;

  static const String kConfigTypeStr;
  static const String kConfigTypeUInt16;
  static const String kConfigTypeUInt32;

  static const String kResponseSuccess;
  static const String kResponseFailure;

  // Get the version
  void onCommandVersion() { m_strResponse = s_strVersion; }

  // Blink the builtin LED.
  void onCommandBlink() {
    digitalWrite(LED_BUILTIN, HIGH);
    delay(100);
    digitalWrite(LED_BUILTIN, LOW);
    delay(100);
    digitalWrite(LED_BUILTIN, HIGH);
    delay(100);
    digitalWrite(LED_BUILTIN, LOW);
  }

  // Get configuration values
  void onCommandGetConfig() {
    // Get the configuration of the panels
    // Up
    m_strResponse.append(s_panelUp.m_orientation);
    m_strResponse.append(',');
    m_strResponse.append(s_panelUp.getNorthSensor().getPin());
    m_strResponse.append(',');
    m_strResponse.append(s_panelUp.getEastSensor().getPin());
    m_strResponse.append(',');
    m_strResponse.append(s_panelUp.getSouthSensor().getPin());
    m_strResponse.append(',');
    m_strResponse.append(s_panelUp.getWestSensor().getPin());
    m_strResponse.append(',');

    // Down
    m_strResponse.append(s_panelDown.m_orientation);
    m_strResponse.append(',');
    m_strResponse.append(s_panelDown.getNorthSensor().getPin());
    m_strResponse.append(',');
    m_strResponse.append(s_panelDown.getEastSensor().getPin());
    m_strResponse.append(',');
    m_strResponse.append(s_panelDown.getSouthSensor().getPin());
    m_strResponse.append(',');
    m_strResponse.append(s_panelDown.getWestSensor().getPin());
    m_strResponse.append(',');

    // Left
    m_strResponse.append(s_panelLeft.m_orientation);
    m_strResponse.append(',');
    m_strResponse.append(s_panelLeft.getNorthSensor().getPin());
    m_strResponse.append(',');
    m_strResponse.append(s_panelLeft.getEastSensor().getPin());
    m_strResponse.append(',');
    m_strResponse.append(s_panelLeft.getSouthSensor().getPin());
    m_strResponse.append(',');
    m_strResponse.append(s_panelLeft.getWestSensor().getPin());
    m_strResponse.append(',');

    // Right
    m_strResponse.append(s_panelRight.m_orientation);
    m_strResponse.append(',');
    m_strResponse.append(s_panelRight.getNorthSensor().getPin());
    m_strResponse.append(',');
    m_strResponse.append(s_panelRight.getEastSensor().getPin());
    m_strResponse.append(',');
    m_strResponse.append(s_panelRight.getSouthSensor().getPin());
    m_strResponse.append(',');
    m_strResponse.append(s_panelRight.getWestSensor().getPin());
    m_strResponse.append(',');

    // Other config items
    m_strResponse.append(Configuration::getInstance()->toString());

    if (m_strResponse[m_strResponse.length() - 1] == ',') {
      m_strResponse.remove(m_strResponse.length() - 1);
    }
  }

  // Set a configuration value. The sender must provide an additional line:
  // `TYPE KEY=VALUE\n`, where `TYPE` is `str`, `u16`, or `u32`.
  void onCommandSetConfig() {
    String strType = Serial.readStringUntil(' ');
    String strKey = Serial.readStringUntil('=');
    String strValue = Serial.readStringUntil('\n');
    if (strType.equalsIgnoreCase(kConfigTypeStr)) {
      Configuration::getInstance()->setString(strKey, strValue);
      m_strResponse = kResponseSuccess;
    } else if (strType.equalsIgnoreCase(kConfigTypeUInt16)) {
      Configuration::getInstance()->setUInt16(strKey, atoi(strValue.c_str()));
      m_strResponse = kResponseSuccess;
    } else if (strType.equalsIgnoreCase(kConfigTypeUInt32)) {
      Configuration::getInstance()->setUInt32(strKey, atoi(strValue.c_str()));
      m_strResponse = kResponseSuccess;
    } else {
      m_strResponse = kResponseFailure;
    }
  }

  // Save configuration items to EEPROM
  void onCommandPersist() { Configuration::getInstance()->write(); }

  // Reset configuration items in memory
  void onCommandReset() { Configuration::getInstance()->reset(); }

  // Get the raw values and thresholds for each sensor
  void onCommandGetValues() {
    for (auto const& panel :
         {s_panelUp, s_panelDown, s_panelLeft, s_panelRight}) {
      for (auto const& sensor :
           {panel.getNorthSensor(),
            panel.getEastSensor(),
            panel.getSouthSensor(),
            panel.getWestSensor()}) {
        m_strResponse.append(sensor.getPressure());
        m_strResponse.append(',');
        m_strResponse.append(sensor.getTriggerThreshold());
        m_strResponse.append(',');
        m_strResponse.append(sensor.getReleaseThreshold());
        m_strResponse.append(',');
      }
    }

    // Remove trailing comma
    m_strResponse.remove(m_strResponse.length() - 1);
  }

  String m_strCommand, m_strResponse;
};

const String SerialProcessor::kCmdVersion = "version";
const String SerialProcessor::kCmdBlink = "blink";
const String SerialProcessor::kCmdGetConfig = "config";
const String SerialProcessor::kCmdSetConfig = "set";
const String SerialProcessor::kCmdPersist = "persist";
const String SerialProcessor::kCmdReset = "reset";
const String SerialProcessor::kCmdValues = "v";
const String SerialProcessor::kCmdCalibrate = "calibrate";

const String SerialProcessor::kResponseSuccess = "!";
const String SerialProcessor::kResponseFailure = "?";

const String SerialProcessor::kConfigTypeStr = "str";
const String SerialProcessor::kConfigTypeUInt16 = "u16";
const String SerialProcessor::kConfigTypeUInt32 = "u32";

static SerialProcessor s_serialProcessor;

// void updateJoystick()
// {
//     Joystick.button(JOY_UP_BUTTON, s_panelUp.isPressed());
//     Joystick.button(JOY_DOWN_BUTTON, s_panelDown.isPressed());
//     Joystick.button(JOY_LEFT_BUTTON, s_panelLeft.isPressed());
//     Joystick.button(JOY_RIGHT_BUTTON, s_panelRight.isPressed());
//     Joystick.send_now();
// }

void updateKeyboard() {
  if (s_panelUp.isPressed()) {
    Keyboard.press('w');
  } else {
    Keyboard.release('w');
  }
  if (s_panelDown.isPressed()) {
    Keyboard.press('s');
  } else {
    Keyboard.release('s');
  }
  if (s_panelLeft.isPressed()) {
    Keyboard.press('a');
  } else {
    Keyboard.release('a');
  }
  if (s_panelRight.isPressed()) {
    Keyboard.press('d');
  } else {
    Keyboard.release('d');
  }
  Keyboard.send_now();
}

static elapsedMicros s_timeSinceJoystickUpdate;
static elapsedMicros s_timeSinceLEDUpdate;

const uint32_t kMicrosPerSecond = 1000000;

static const String kAutoLights("auto_lights");

void loop() {
  // It takes about 17us to sample each sensor (taking the average of 4
  // readings within the analogRead() call), so with 16 sensors we can read
  // all panels about 3 times and still have about 150-200us left for lights,
  // so read intervals should be very consistent.
  updatePanels();
  s_serialProcessor.update();

  // Limit frequency of joystick reports
  if (
    s_timeSinceJoystickUpdate >= kMicrosPerSecond / kJoystickUpdateFrequency) {
    s_timeSinceJoystickUpdate -= kMicrosPerSecond / kJoystickUpdateFrequency;
    // updateJoystick();
    updateKeyboard();
  }

  // Limit frequency of LEDs
  if (s_timeSinceLEDUpdate >= kMicrosPerSecond / kLEDUpdateFrequency) {
    s_timeSinceLEDUpdate -= kMicrosPerSecond / kLEDUpdateFrequency;
    if (Configuration::getInstance()->getUInt16(kAutoLights, 0) > 0) {
      Lights::getInstance()->setStatus(
        enumLightsLeftArrow, s_panelLeft.isPressed());
      Lights::getInstance()->setStatus(
        enumLightsRightArrow, s_panelRight.isPressed());
      Lights::getInstance()->setStatus(
        enumLightsUpArrow, s_panelUp.isPressed());
      Lights::getInstance()->setStatus(
        enumLightsDownArrow, s_panelDown.isPressed());
    }
    Lights::getInstance()->update();
    FastLED.show();
  }

  // printSensorValues();
}

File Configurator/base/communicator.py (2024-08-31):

"""Communicate with the board firmware.
"""

from enum import Enum
from typing import Mapping, Tuple, Union
import serial


class PanelOrientation(Enum):
    """Orientation of the Arrow Panel PCB within an panel. Based on
    counterclockwise rotation.
    """

    Standard = 0
    Rotated90Degrees = 90
    Rotated180Degrees = 180
    Rotated270Degrees = 270

    @staticmethod
    def from_degrees(degrees: int) -> Enum:
        """Get PanelOrientation enumeration based on degrees.
        """
        try:
            return {
                0: PanelOrientation.Standard,
                90: PanelOrientation.Rotated90Degrees,
                180: PanelOrientation.Rotated180Degrees,
                270: PanelOrientation.Rotated270Degrees,
            }[degrees]
        except KeyError:
            raise KeyError(f'Invalid panel orientation: {degrees}')


class Color:

    @staticmethod
    def from_int(value: int) -> Tuple[int, int, int]:
        return (value & 0xFF, (value >> 8) & 0xFF, (value >> 16) & 0xFF)

    @staticmethod
    def to_int(color: Tuple[int, int, int]) -> int:

        if len(color) != 3:
            raise ValueError("`color` must be a 3-tuple")

        for component in range(len(color)):
            value = color[component]
            if value < 0 or value > 255:
                raise ValueError(
                    '{component} component of color must be in range [0, 255].'.format(
                        component='RGB'[component]
                    ))

        return color[0] | (color[1] << 8) | (color[2] << 16)


class Communicator:
    """Communicate with the board firmware.
    """

    COMMAND_VERSION = 'version'
    COMMAND_BLINK = 'blink'
    COMMAND_GETCONFIG = 'config'
    COMMAND_SETCONFIG = 'set'
    COMMAND_PERSIST = 'persist'
    COMMAND_VALUES = 'v'
    COMMAND_CALIBRATE = 'calibrate'

    CONFIG_TYPE_STRING = 'str'
    CONFIG_TYPE_U16 = 'u16'
    CONFIG_TYPE_U32 = 'u32'

    RESPONSE_SUCCESS = '!'
    RESPONSE_FAILURE = '?'

    DIRECTIONS = {'up', 'down', 'left', 'right'}
    CONFIG_VALUE_TYPES = {CONFIG_TYPE_STRING, CONFIG_TYPE_U16, CONFIG_TYPE_U32}

    def __init__(
        self,
        ser: Union[serial.Serial, str],
    ) -> None:
        """Communicate with the firmware using a serial interface.

        Args:
            ser: Serial object
        """
        if isinstance(ser, str):
            ser = serial.Serial(ser)

        self._ser = ser

    def __send_line(self, line: str) -> None:
        """Send line terminated with newline character.

        Args:
            line: The line to send.
        """
        self._ser.write(f'{line}\n'.encode('ascii'))

    def __get_line(self) -> str:
        """Get ASCII-encoded line from the device.
        """
        line = self._ser.readline().decode('ascii').strip()
        return line

    def __send_command(self, command: str) -> None:
        """Send command to the device.

        Args:
            command: Command string.
        """
        self.__send_line(f'-{command}')

    def __set_config(self, value_type: str, key: str, value) -> None:
        """Set a configuration item.

        Args:
            value_type: One of {`str`, `u16`, `u32`}.
            key: Name of configuration item.
            value: The value to set the configuration item to.
        """
        if value_type not in self.CONFIG_VALUE_TYPES:
            raise ValueError(
                f"`value_type` must be one of {', '.join(self.CONFIG_VALUE_TYPES)}")
        self.__send_command(self.COMMAND_SETCONFIG)
        self.__send_line(f'{value_type} {key}={value}')
        response = self.__get_line()

        if not response in {
            Communicator.RESPONSE_SUCCESS,
            Communicator.RESPONSE_FAILURE
        }:
            raise ValueError(f'Unexpected response: {response}')

        if response != self.RESPONSE_SUCCESS:
            raise ValueError(
                f'Failed to set config {key}[{value_type}]={value}')

    def __set_config_u16(self, key: str, value) -> None:
        """Set a configuration item for an unsigned 16-bit integer.

        Args:
            key: Name of the configuration item.
            value: The value to set the configuration item to.
        """
        self.__set_config(self.CONFIG_TYPE_U16, key, value)

    def __set_config_u32(self, key: str, value) -> None:
        """Set a configuration item for an unsigned 32-bit integer.

        Args:
            key: Name of the configuration item.
            value: The value to set the configuration item to.
        """
        self.__set_config(self.CONFIG_TYPE_U32, key, value)

    def __set_config_str(self, key: str, value) -> None:
        """Set a configuration item for a string.

        Args:
            key: Name of the configuration item.
            value: The value to set the configuration item to.
        """
        self.__set_config(self.CONFIG_TYPE_STRING, key, value)

    def get_version(self) -> str:
        """Get firmware version string.
        """
        self.__send_command(self.COMMAND_VERSION)
        return self.__get_line()

    def blink_led(self) -> None:
        """Blink the on-board LED on the Teensy board.
        """
        self.__send_command(self.COMMAND_BLINK)

    def calibrate(self) -> None:
        """Force calibration of the sensors.
        """
        self.__send_command(self.COMMAND_CALIBRATE)

    def set_thresholds(self, pin: int, trigger: int, release: int) -> None:
        """Set the tresholds for a sensor.

        Args:
            pin: Pin on the Teensy connected to the sensor.
            trigger: Value above baseline to trigger a hit.
            release: Value above baseline to trigger a release.

        Returns:
            True if the threshold was set successfully. Otherwise, False.
        """
        if not 0 < trigger < 1024:
            raise ValueError('`trigger` must be in range [0, 1024).')
        if not 0 < release < 1024:
            raise ValueError('`release` must be in range [0, 1024).')
        if release > trigger:
            raise ValueError(
                f'trigger ({trigger}) must be greater than or equal to release ({release})')

        key_name = f'sensor{pin}'

        self.__set_config_u16(key_name + 'trigger', trigger)
        self.__set_config_u16(key_name + 'release', release)

    def get_config(self) -> Mapping[str, Enum]:
        """Get configuration.

        Returns:
            Dictionary of configuration items.
        """
        self.__send_command(self.COMMAND_GETCONFIG)
        response = self.__get_line()
        split = response.split(',')

        key_value_entries = dict(entry.split('=') for entry in split[20:])
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

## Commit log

2020-11-25 Add frame.
    [1604978066103.0001.ipt, 1604978066103.ipt, 1604978066131.0001.ipt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]
2020-11-25 Add image of frame to README.md.
2020-11-25 Remove old bill of materials.
    [8020 BOM.ods]
2020-11-25 Update Arrow schematic. Add schematic images.
    [DDR Pad.sch]
2020-11-25 Add README.md to PCB projects.
2020-12-06 Change PCB orientation. Ignore lights for now.
2020-12-24 Use per-sensor thresholds.
2020-12-24 Cleanup and fix warnings.
    [main.cpp]
2020-12-24 Remove unneded calibration.
    The sensors will automatically calibrate the first time update() is called.
2020-12-24 Load UI from .ui file. Add combobox for devices.
2020-12-25 Get trigger/release setting at each calibration.
2020-12-25 Refactor retrieving sensor status.
2020-12-25 Report pins used for sensors.
    Can be used to set config values referencing pin numbers (i.e. the trigger/release thresholds for each sensor).
2020-12-27 Plot data for 16 sensors
2020-12-28 Convert config to singleton. Bug fixes.
    [main.cpp]
2020-12-28 Read values from serial device.
2021-01-09 Calibrate panels in setup().
2021-01-13 Reset sensor after calibrating.
2021-01-13 Cleanup calibrate command.
2021-01-13 Add button to calibrate pad.
2021-01-13 Don't print FPS.
2021-01-13 Add lighting code.
    Decode light data and use FastLED with a OctoWS2812B-derived controller to drive LEDs in each panel.
2021-01-20 Fix left panel orientation.
    [main.cpp]
2021-01-22 Color-correct lights for more accurate colors.
    Colors chosen in the configurator are much closer to the lights show in the pad now!
    [main.cpp]
2021-01-26 Add comment about ADC read times.
2022-11-21 Don't write when resetting.
    [main.cpp]
2023-04-06 Set individual trigger/release thresholds. Add persist button.
2023-11-22 Remove prints from lights_bridge.py
    Was leading to latency regression.

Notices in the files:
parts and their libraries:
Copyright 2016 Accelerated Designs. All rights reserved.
